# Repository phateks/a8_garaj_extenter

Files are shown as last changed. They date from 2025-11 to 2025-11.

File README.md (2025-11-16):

# Kincony A8 - 14 Inputs Extender 

> **_NOTE:_**  **The address of the MCP is fixed to 0x20**

**BOM is not created in the files**

3v3 - TSR2-2433N - TracoPower

For TCMT1100 Anod connection i used 1.8K Ohm with 12VDC input - 0805

For TCMT1100 Emitter connection i used 4.7K Ohm for pullup on 3v3. - 0805

Capacitor 100nF - 1026

2 x Connector 1x7 - 1823683 - PhoenixContact

> **_NOTE:_**  **There are no I2C resistors on the board, if this is used for somethig else they must be placed somewhere else if needed**

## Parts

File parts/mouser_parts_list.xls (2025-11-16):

A8_GARAJ_EXTENDER
Mouser No | Mfr. No | Manufacturer | Customer No | Description | RoHS | Lifecycle | Order Qty. | Price (RON) | Ext.: (RON)
651-1823683 | 1823683 | Phoenix Contact |  | Fixed Terminal Blocks SPT-THR 1 5/ 7-H-3 5 P20 R44 | RoHS Compliant |  | 2 | 19,77 RON | 39,54 RON
71-CRCW0805-1.8K-E3 | CRCW08051K80FKEA | Vishay |  | Thick Film Resistors - SMD 1/4W 1.8Kohms 1% 100ppm | RoHS Compliant By Exemption |  | 20 | 0,101 RON | 2,02 RON
495-TSR2-2433N | TSR 2-2433N | TRACO Power |  | DC/DC Converters - Through Hole 4.6-36Vin 3.3Vout 2A SIP-3 POL | RoHS Compliant | New Product | 1 | 28,57 RON | 28,57 RON
71-CRCW08054K70FKEC | CRCW08054K70FKEC | Vishay |  | Thick Film Resistors - SMD D12/CRCW0805 100 4K7 1% ET6 e3 | RoHS Compliant By Exemption |  | 20 | 0,191 RON | 3,82 RON

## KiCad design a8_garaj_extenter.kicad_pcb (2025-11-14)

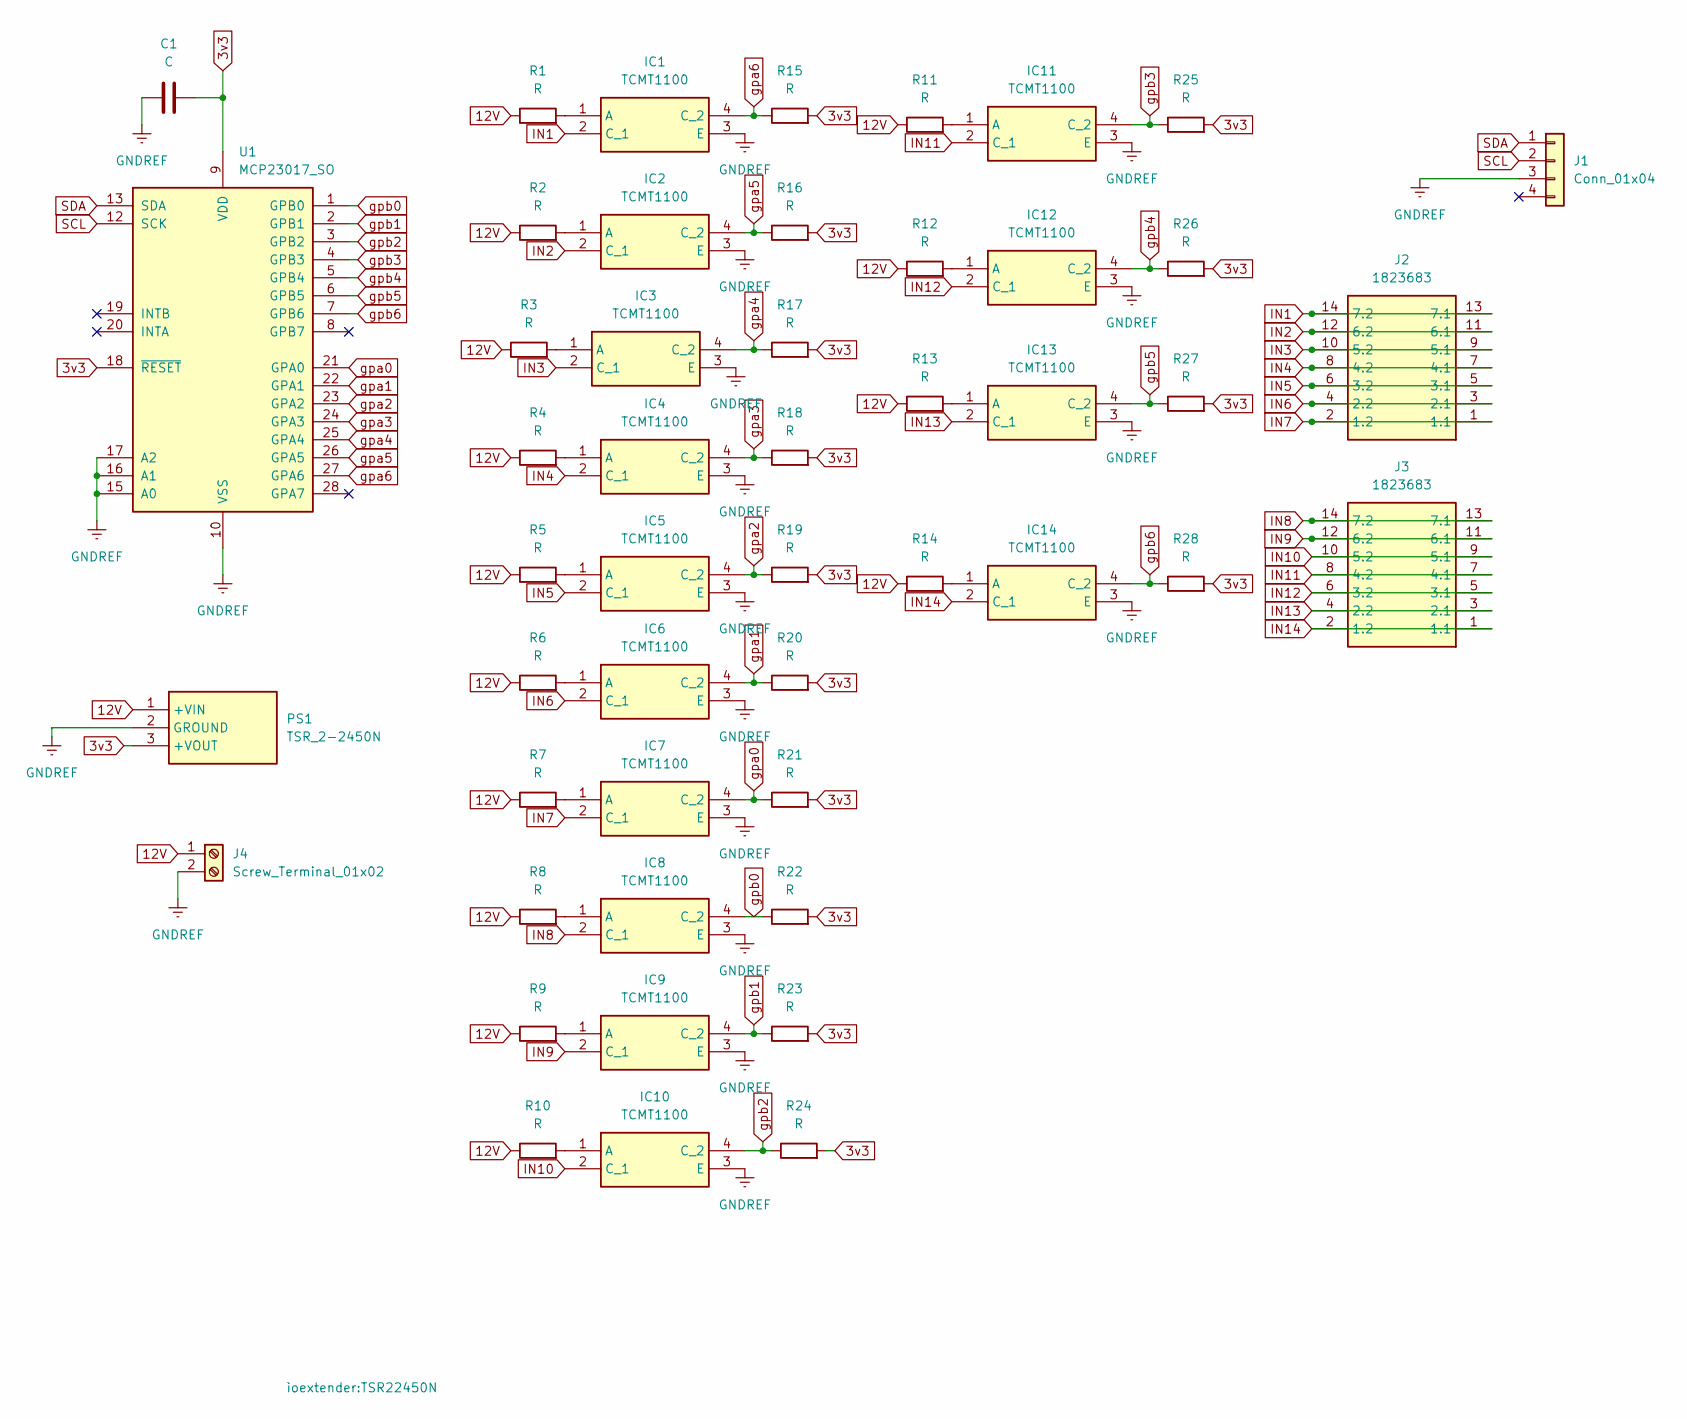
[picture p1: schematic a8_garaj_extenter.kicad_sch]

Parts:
C1: C; C_1206_3216Metric_Pad1.33x1.80mm_HandSolder
IC1, IC2, IC3, IC4, IC5, IC6, IC7, IC8, IC9, IC10, IC11, IC12, IC13, IC14: TCMT1100; opto_tcmt1100; Manufacturer_Part_Number TCMT1100; Mouser Part Number 782-TCMT1100
J1: Conn_01x04; JST_XA_B04B-XASK-1_1x04_P2.50mm_Vertical
J2, J3: 1823683; Manufacturer_Part_Number 1823683; Mouser Part Number 651-1823683
J4: Screw_Terminal_01x02; TerminalBlock_MetzConnect_Type059_RT06302HBWC_1x02_P3.50mm_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
PS1: TSR_2-2450N; TSR22450N; Manufacturer_Part_Number TSR 2-2450N; Mouser Part Number 495-TSR2-2450N
R1, R2, R3, R4, R5, R6, R7, R8, R9, R10, R11, R12, R13, R14, R15, R16, R17, R18, R19, R20, R21, R22, R23, R24, R25, R26, R27, R28: R; R_0805_2012Metric_Pad1.20x1.40mm_HandSolder
U1: MCP23017_SO; SOIC-28W_7.5x17.9mm_P1.27mm

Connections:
3v3: C1.2, PS1.3 (+VOUT), R15.2, R16.2, R17.2, R18.2, R19.2, R20.2, R21.2, R22.2, R23.2, R24.2, R25.2, R26.2, R27.2, R28.2, U1.9 (VDD), U1.18 (~RESET)
12V: J4.1, PS1.1 (+VIN), R1.1, R2.1, R3.1, R4.1, R5.1, R6.1, R7.1, R8.1, R9.1, R10.1, R11.1, R12.1, R13.1, R14.1
GNDREF: C1.1, IC1.3 (E), IC2.3 (E), IC3.3 (E), IC4.3 (E), IC5.3 (E), IC6.3 (E), IC7.3 (E), IC8.3 (E), IC9.3 (E), IC10.3 (E), IC11.3 (E), IC12.3 (E), IC13.3 (E), IC14.3 (E), J1.3, J4.2, PS1.2 (GROUND), U1.10 (VSS), U1.15 (A0), U1.16 (A1), U1.17 (A2)
IN1: IC1.2 (C_1), J2.13 (7.1), J2.14 (7.2)
IN2: IC2.2 (C_1), J2.11 (6.1), J2.12 (6.2)
IN3: IC3.2 (C_1), J2.9 (5.1), J2.10 (5.2)
IN4: IC4.2 (C_1), J2.7 (4.1), J2.8 (4.2)
IN5: IC5.2 (C_1), J2.5 (3.1), J2.6 (3.2)
IN6: IC6.2 (C_1), J2.3 (2.1), J2.4 (2.2)
IN7: IC7.2 (C_1), J2.1 (1.1), J2.2 (1.2)
IN8: IC8.2 (C_1), J3.13 (7.1), J3.14 (7.2)
IN9: IC9.2 (C_1), J3.11 (6.1), J3.12 (6.2)
IN10: IC10.2 (C_1), J3.9 (5.1), J3.10 (5.2)
IN11: IC11.2 (C_1), J3.7 (4.1), J3.8 (4.2)
IN12: IC12.2 (C_1), J3.5 (3.1), J3.6 (3.2)
IN13: IC13.2 (C_1), J3.3 (2.1), J3.4 (2.2)
IN14: IC14.2 (C_1), J3.1 (1.1), J3.2 (1.2)
unnamed: IC1.1 (A), R1.2
unnamed: IC2.1 (A), R2.2
unnamed: IC3.1 (A), R3.2
unnamed: IC4.1 (A), R4.2
unnamed: IC5.1 (A), R5.2
unnamed: IC6.1 (A), R6.2
unnamed: IC7.1 (A), R7.2
unnamed: IC8.1 (A), R8.2
unnamed: IC9.1 (A), R9.2
unnamed: IC10.1 (A), R10.2
unnamed: IC11.1 (A), R11.2
unnamed: IC12.1 (A), R12.2
unnamed: IC13.1 (A), R13.2
unnamed: IC14.1 (A), R14.2
SCL: J1.2, U1.12 (SCK)
SDA: J1.1, U1.13 (SDA)
gpa0: IC7.4 (C_2), R21.1, U1.21 (GPA0)
gpa1: IC6.4 (C_2), R20.1, U1.22 (GPA1)
gpa2: IC5.4 (C_2), R19.1, U1.23 (GPA2)
gpa3: IC4.4 (C_2), R18.1, U1.24 (GPA3)
gpa4: IC3.4 (C_2), R17.1, U1.25 (GPA4)
gpa5: IC2.4 (C_2), R16.1, U1.26 (GPA5)
gpa6: IC1.4 (C_2), R15.1, U1.27 (GPA6)
gpb0: IC8.4 (C_2), R22.1, U1.1 (GPB0)
gpb1: IC9.4 (C_2), R23.1, U1.2 (GPB1)
gpb2: IC10.4 (C_2), R24.1, U1.3 (GPB2)
gpb3: IC11.4 (C_2), R25.1, U1.4 (GPB3)
gpb4: IC12.4 (C_2), R26.1, U1.5 (GPB4)
gpb5: IC13.4 (C_2), R27.1, U1.6 (GPB5)
gpb6: IC14.4 (C_2), R28.1, U1.7 (GPB6)

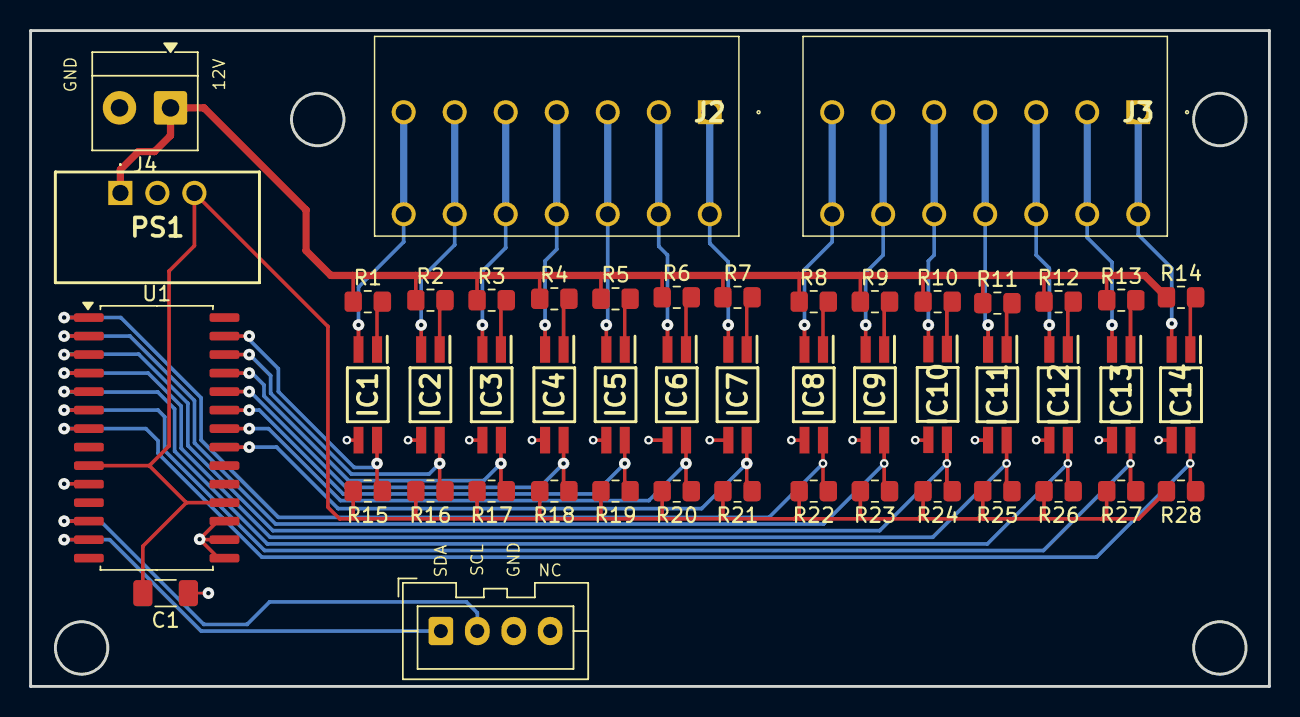
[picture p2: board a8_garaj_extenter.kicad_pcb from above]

Board: 2 copper layers, 85.0 x 45.0 mm, 49 parts (0 on the bottom side), 47 nets.
